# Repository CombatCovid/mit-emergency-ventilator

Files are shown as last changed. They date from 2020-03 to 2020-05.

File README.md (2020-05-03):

---
# basis test for remote pickup of metadata by both client app and 
# the essential repo updates system to come. 
# *todo* ground rules for yaml lines of this file, to be written 

# note carefully that this is the title that will show 
# in the Finder-Viewer app, and so _must_ be short enough to fit
# the longTitle below lets such be in meta; no place to use it at present
shortTitle: MIT Emergency Ventilator (E-Vent)
# these names are fixed labels as must be used on repo by GitHub API, for our access
name: mit-emergency-ventilator
nameWithOwner: CombatCovid/mit-emergency-ventilator

# markdown titles too long for Finder to show especially, we hold for any uses
# the same for long descriptions in the languages
# when text may fit, then they are the same in topic and longTopic yaml items
longTitle: MIT Emergency Ventilator (E-Vent) Project

languages:
  EN:
    description: A low-cost ventilator, based on the collective wisdom of many clinicians
    keywords: [patient,recovery,critical care,intensive care,icu,equipment,
      emergency room,helper,treatment,hospital,operating room]
    longDescription: >
      A ventilator is a machine that provides mechanical ventilation 
      by moving breathable air into and out of the lungs, to deliver breaths
      to a patient who is physically unable to breathe, 
      or breathing insufficiently.

  ES:
    description: Un ventilador de bajo costo, basado en la sabiduría colectiva de muchos médicos.
    keywords: [ paciente,recuperación,Cuidado crítico,
      cuidados intensivos,icu,equipo,sala de emergencias,
      ayudante,tratamiento,hospital,sala de operaciones ]
    longDescription: >
      Un ventilador es una máquina que proporciona ventilación mecánica.
      moviendo aire respirable dentro y fuera de los pulmones, 
      para entregar respiraciones a un paciente que es físicamente 
      incapaz de respirar, o respirando insuficientemente.
      
  KR:
    keywords: [ 환자,회복,중요한 치료,집중 치료,아이쿠,장비,
      응급실,돕는 사람,치료,병원,수술실 ]
    description: 많은 임상의의 집단적 지혜에 기반한 저렴한 인공 호흡기
    longDescription: >
      인공 호흡기는 기계적 환기를 제공하는 기계입니다
      통기성 공기를 폐 안팎으로 이동시켜 호흡
      신체적으로 숨을 쉴 수없는 환자에게
      또는 호흡이 불충분합니다.
 
project-link: https://e-vent.mit.edu/
intended-use: >-
    tbd
made: true
made-independently: false
license:
  hardware: undefined
okh-manifest-version: 1.0.0
date-updated: 2020-03-31
manifest-author:
  name: MiT people
  affiliation: MIT
contributors:
  undefined
sub-parts:
  undefined
  undefined
  
---

# Title: MIT Emergency Ventilator (E-Vent) Project

### References: 

All the information compiled here is from the [MIT Emergency Ventilator (E-Vent) Project](https://e-vent.mit.edu/)

To download our repo: [**DOWNLOAD**](https://github.com/CombatCovid/mit-emergency-ventilator/archive/master.zip)

This is the url of our repo : [https://github.com/CombatCovid/mit-emergency-ventilator](https://github.com/CombatCovid/mit-emergency-ventilator)

## Background & Need

We are one of several teams who recognized the challenges faced by Italian physicians, and are working to find a solution to the anticipated global lack of ventilators. In the US alone, the COVID-19 pandemic may cause ventilator shortages on the order of 300,000-700,000 units (CDC Pandemic Response Plans). These could present on a national scale within weeks, and are already being felt in certain areas. An increase in conventional ventilator production is very likely to fall short and with significant associated cost (paywall warning).

Almost every bed in a hospital has a manual resuscitator (Ambu-Bag) nearby, available in the event of a rapid response or code where healthcare workers maintain oxygenation by squeezing the bag. Automating this appears to be the simplest strategy that satisfies the need for low-cost mechanical ventilation, with the ability to be rapidly manufactured in large quantities. However, doing this safely is not trivial.

Use of a bag-valve mask (BVM) in emergency situations is not a new concept. A portable ventilator utilizing an ambu-bag was introduced in 2010 by a student team in the MIT class 2.75 Medical Device Design (original paper here and news story here), but did not move past the prototype stage. Around the same time, a team from Stanford developed a lower-cost ventilator for emergency stockpiles and the developing world. It looks similar to a modern ICU ventilator (Onebreath), but “production for US hospitals would start [in] about 11 months”, making it “a second wave solution” (MIT Tech Review Article). Last year, the AMBU® Bag concept was re-visited by two student teams, one from Rice university (here & here), and another Boston-based team who won MIT Sloan’s Healthcare prize (MIT News: Umbilizer). Other teams currently working on this challenge can be found linked on our “Additional Resources” page.

## Key Research Question

We have launched an emergency research project with a team of MIT Engineers and American clinicians to address the question:

**Is it possible to safely ventilate a COVID-19 patient by automatically actuating a manual resuscitator?**

Our process in approaching this question is to first identify the minimum requirements for a low-cost ventilator, based on the collective wisdom of many clinicians, design against these requirements, conduct immediate testing, report the results, iterate and facilitate discussion.

Manual ventilation with an Ambu-bag is a short-term solution in a critical care environment, without any apparent clinical evidence regarding the safety of long-term use (days-weeks). There are multiple scenarios in which respiratory support could be needed: patients can be awake or asleep, sedated or sedated and paralyzed, breathing spontaneously, weaning off of a vent, etc. Furthermore, changing clinical presentations with ARDS require shifting minute ventilation (tidal volume x respiratory rate) to “lung-protective” strategies, which place patient’s at risk for things like auto-PEEP. Some of these situations are simpler than others, with the simplest being ventilating a sedated, paralyzed patient, and at a minimum a safe emergency ventilator could be used in such a situation to free-up a conventional ventilator.

Any solution should be utilized only in a healthcare setting with direct monitoring by a clinical professional. While it cannot replace an FDA-approved ICU ventilator, in terms of functionality, flexibility, and clinical efficacy, the MIT E-Vent is anticipated to have utility in helping free up existing supply or in life-or-death situations when there is no other option.

Further, any low-cost ventilator system must take great care regarding providing clinicians with the ability to closely control and monitor tidal volume, inspiratory pressure, bpm, and I/E ratio, and be able to provide additional support in the form of PEEP, PIP monitoring, filtration, and adaptation to individual patient parameters. We recognize, and would like to highlight for anyone seeking to manufacture a low-cost emergency ventilator, that failing to properly consider these factors can result in serious long-term injury or death.

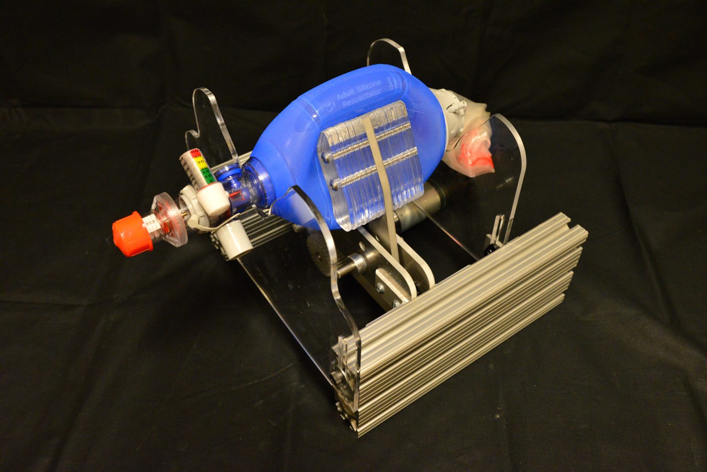
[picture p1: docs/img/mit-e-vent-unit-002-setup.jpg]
MIT E-vent Unit 002 setup


## Open Source Design
At the present time, we are producing four sets of material, which we will be releasing and updating on this site in an open-source fashion:

1. Minimum safe ventilator functionality based on clinical guidance
2. Reference hardware design for meeting minimum clinical requirements
3. Reference control strategies and electronics designs and supporting insights
4. Results from testing in animal models

We are releasing this material with the intent to provide those with the ability to make or manufacture ventilators, the tools needed to do so in a manner that seeks to ensure patient safety. Clinicians viewing this site can provide input and expertise and report on their efforts to help their patients.

As with any research to design to scale-up to manufacture, we anticipated that there will be many problems and it is our goal to provide this site as a tool to “close the loop” and receive feedback. We will also do our best to publish the most relevant pieces of information in the discussion forum for all to see.

We invite anyone who is interested to follow this work.

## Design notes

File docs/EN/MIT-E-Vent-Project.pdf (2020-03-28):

# MIT Emergency Ventilator (E-Vent) Project

## Contents

1 Title: MIT Emergency Ventilator (E-Vent) Project | 2
1.0.1 | References: | | 2
1.1 Background & Need | | 2
1.2 Key Research Question | | 2
1.3 Open Source Design | | 3
2 Key Ventilation Specifications | 4
3 Mechanical design | 4
3.1 Files to download | | 5
3.2 Documentation useful pictures | | 5
3.2.1 | Early design (Unit 001) | | 9
4 Electrical Design | 9
4.1 Motor & Encoder | | 9
4.1.1 | Motor Options: | | 9
4.2 Power Supply | | 13
4.3 Controller | | 14
4.4 Motor Driver | | 14
4.5 Inputs | | 14
4.6 Output | | 15
4.7 Audible alert buzzer will identify multiple fault conditions | | 15
5 Testing results | 16
5.1 Study 1 – 20 March 2020 | | 16
5.1.1 | Key Learnings (more results will be forthcoming) | | 16
5.1.2 | Next Steps | | 16

## List of Figures

1 | MIT E-vent Unit 002 setup | | 3
2 | Plates to support the bag | | 10
3 | Unit 002-most updated design | | 11
4 | Electrical System Architecture | | 12
5 | Andy Mark AM 2971 gearmotor | | 13
6 | RoboClaw Solo motor controller | | 15

## 1 Title: MIT Emergency Ventilator (E-Vent) Project

### 1.0.1 References:

All the information compiled here is from the MIT Emergency Ventilator (E-Vent) Project (https://e-vent.mit.edu/)

To download our repo: DOWNLOAD (https://github.com/CombatCovid/mit-emergency-ventilator/archive/master.zip)

This is the url of our repo : https://github.com/CombatCovid/mit-emergency-ventilator

### 1.1 Background & Need

We are one of several teams who recognized the challenges faced by Italian physicians, and are working to find a solution to the anticipated global lack of ventilators. In the US alone, the COVID-19 pandemic may cause ventilator shortages on the order of 300,000-700,000 units (CDC Pandemic Response Plans). These could present on a national scale within weeks, and are already being felt in certain areas. An increase in conventional ventilator production is very likely to fall short and with significant associated cost (paywall warning).

Almost every bed in a hospital has a manual resuscitator (Ambu-Bag) nearby, available in the event of a rapid response or code where healthcare workers maintain oxygenation by squeezing the bag. Automating this appears to be the simplest strategy that satisfies the need for low-cost mechanical ventilation, with the ability to be rapidly manufactured in large quantities. However, doing this safely is not trivial.

Use of a bag-valve mask (BVM) in emergency situations is not a new concept. A portable ventilator utilizing an ambu-bag was introduced in 2010 by a student team in the MIT class 2.75 Medical Device Design (original paper here and news story here), but did not move past the prototype stage. Around the same time, a team from Stanford developed a lower-cost ventilator for emergency stockpiles and the developing world. It looks similar to a modern ICU ventilator (Onebreath), but “production for US hospitals would start [in] about 11 months”, making it “a second wave solution” (MIT Tech Review Article). Last year, the AMBU® Bag concept was re-visited by two student teams, one from Rice university (here & here), and another Boston-based team who won MIT Sloan’s Healthcare prize (MIT News: Umbilizer). Other teams currently working on this challenge can be found linked on our “Additional Resources” page.

### 1.2 Key Research Question

We have launched an emergency research project with a team of MIT Engineers and American clinicians to address the question:

Is it possible to safely ventilate a COVID-19 patient by automatically actuating a manual resuscitator?

Our process in approaching this question is to first identify the minimum requirements for a low-cost ventilator, based on the collective wisdom of many clinicians, design against these requirements, conduct immediate testing, report the results, iterate and facilitate discussion.

Manual ventilation with an Ambu-bag is a short-term solution in a critical care environment, without any apparent clinical evidence regarding the safety of long-term use (days-weeks). There are multiple scenarios in which respiratory support could be needed: patients can be awake or asleep, sedated or sedated and paralyzed, breathing spontaneously, weaning off of a vent, etc. Furthermore, changing clinical presentations with ARDS require shifting minute ventilation (tidal volume x respiratory rate) to “lung-protective” strategies, which place patient’s at risk for things like auto-PEEP. Some of these situations are simpler than others, with the simplest being ventilating a sedated, paralyzed patient, and at a minimum a safe emergency ventilator could be used in such a situation to free-up a conventional ventilator.

Any solution should be utilized only in a healthcare setting with direct monitoring by a clinical professional. While it cannot replace an FDA-approved ICU ventilator, in terms of functionality, flexibility, and clinical efficacy, the MIT E-Vent is anticipated to have utility in helping free up existing supply or in life-or-death situations when there is no other option.

Further, any low-cost ventilator system must take great care regarding providing clinicians with the ability to closely control and monitor tidal volume, inspiratory pressure, bpm, and I/E ratio, and be able to provide additional support in the form of PEEP, PIP monitoring, filtration, and adaptation to individual patient parameters. We recognize, and would like to highlight for anyone seeking to manufacture a low-cost emergency ventilator, that failing to properly consider these factors can result in serious long-term injury or death.


Figure 1: MIT E-vent Unit 002 setup

### 1.3 Open Source Design

At the present time, we are producing four sets of material, which we will be releasing and updating on this site in an open-source fashion:

1. Minimum safe ventilator functionality based on clinical guidance
2. Reference hardware design for meeting minimum clinical requirements
3. Reference control strategies and electronics designs and supporting insights
4. Results from testing in animal models

We are releasing this material with the intent to provide those with the ability to make or manufacture ventilators, the tools needed to do so in a manner that seeks to ensure patient safety. Clinicians viewing this site can provide input and expertise and report on their efforts to help their patients.

As with any research to design to scale-up to manufacture, we anticipated that there will be many problems and it is our goal to provide this site as a tool to “close the loop” and receive feedback. We will also do our best to publish the most relevant pieces of information in the discussion forum for all to see.

We invite anyone who is interested to follow this work.

## 2 Key Ventilation Specifications

From the Clinical Guidance this document summarizes the minimum set of requirements for ventilation:

1. Patients must be under the management of a trained clinician.
2. The minimum controllable parameters in order to ventilate a patient include:
- BPM (breaths per minute): between 8 – 30 BPM
- Tidal Volume (air volume pushed into lung): between 200 – 800 mL based on patient weight
- I/E Ratio (inspiratory/expiration time ratio): recommended to start around 1:2; best if adjustable between range of 1:1 – 1:4¹
- Assist Detection pressure. When a patient tries to inspire, they can cause a dip on teh order of 1 – 5 cm H2O, with respect to PEEP pressure (not necessarily = atmospheric).
3. Airway pressure must be monitored
- Maximum pressure should be limited to 40 cm H2O at any time; Plateau pressure should be limited to max 30 cm H2O
- The use of a passive mechanical blow-off valve fixed at 40 cm H2O is strongly recommended
- Clinician require readings of plateau pressure and PEEP (refer to clinical documentation tab)
- PEEP of 5-15 cm H2O required; many patients need 10-15 cmH2O
4. Failure conditions must permit conversion to manual clinician override, i.e. if automatic ventilation fails, the conversion to immediate ventilation must be immediate.
5. Ventilation on room air is better than no ventilation at all. Blending of oxygen and air gas mixture to adjust FiO2 is not important in an emergency scenario. It is certainly nice to have that ability and can easily be implemented with a oxygen / air gas blender that some hospitals already have.
6. Covid-19 can get aerosolized (airborne), so HEPA filtration on the patient’s exhalation is required or between the ventilator unit and the patient (at the end of the endotracheal tube) to protect clinical staff from certain infection. In-line HEPA filters can usually be purchased alongside manual resuscitator bags.
7. Heat and moisture exchanger should be used in line with the breathing circuit.
8. Failure conditions must result in an alarm.

This is a minimal requirement set for emergency use. Equipment designed for more regular use, even if for emerging markets, will require additional features to be used on a regular basis.

## 3 Mechanical design

How does the E-vent looks like?

See how the emergency ventilator works here (https://e-vent.mit.edu/wp-content/uploads/2020/03/002-bench-testing-scaled-1.mp4)

1Range determined based on several COVID-19 patients’ ventilator settings reported from Boston area ICUs

### 3.1 Files to download

Follow this link where there are all the .dxf files.

This section documents the mechanical design of the MIT E-Vent.

Please understand that we are designing, testing and posting information as fast as we can. We have no hidden information and more detailed plans will post as soon as we draw them!

Note: Any mechanical design must meet the specifications outlined in the Getting started section.

This is a prototype. We are in process of testing and refining this concept design to increase robustness. The basic concept consists of two arms that gently close in sync to compress the bag. This must be coupled with a closed loop control system. Major mechanical design requirements included:

- Be nice to your bag and its hoses! Up to 2x7x24X60x30 = 604,800 cycles.
- Fail-Safe operation! If the machine fails, a clinician must be able to convert to manual bagging.
- Keep It Simple & Make It Super! Enable others to fabricate.
- Many drive motor possibilities! Enable multiple motors and configurations.

The Units version 002 shown here were developed to maximize flexibility during testing, so that the bag and motor position could be adjusted. None of this adjustability is needed once a particular bag is selected.

The basic dimensions are now set and any skilled mechanical designer will be able to execute this design and adjust it to suit locally available materials and fabrication technologies.

We have ready access to waterjet and laser cutters and 80/20 components, however these parts can be CNC milled and bolted and welded to your specification

### 3.2 Documentation useful pictures

Caution: Forces and torques are much higher than expected when an Ambu bag is connected to a human respiratory system pressures can range up to 40 cm H2O and, potentially, even higher depending on breath rate. There must be a pressure release valve set at 40 cm H2O; without this higher pressures will risk permeant injury or death. Diseased lungs can have compliance on the order of 10x lower than that of healthy patients and this further compounds the problem.

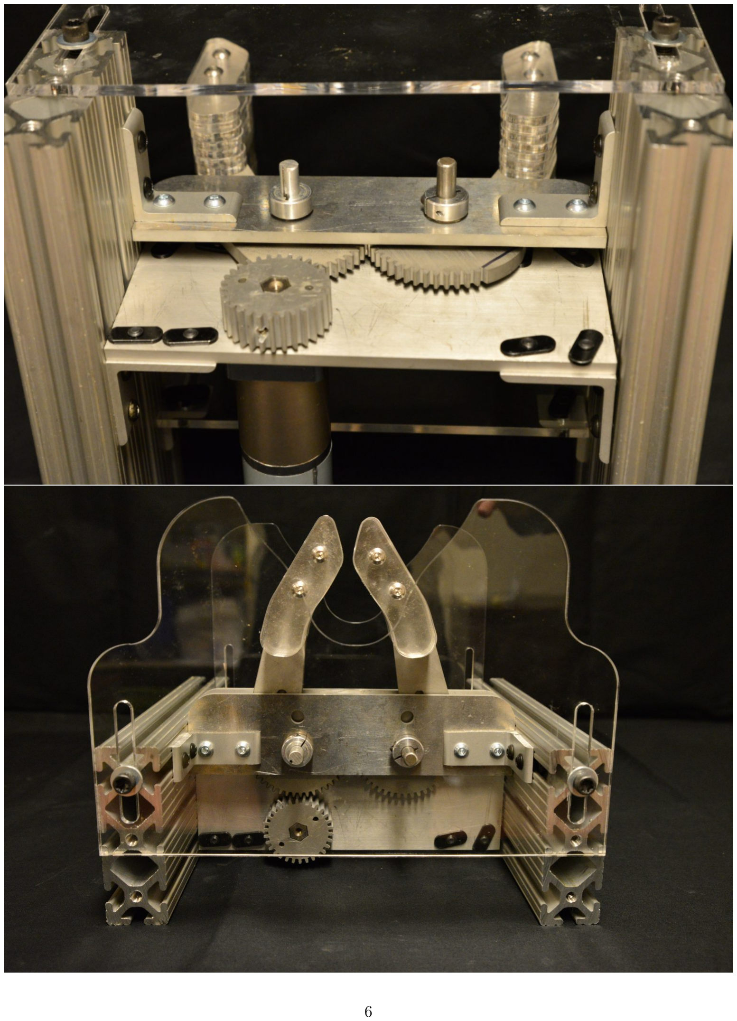
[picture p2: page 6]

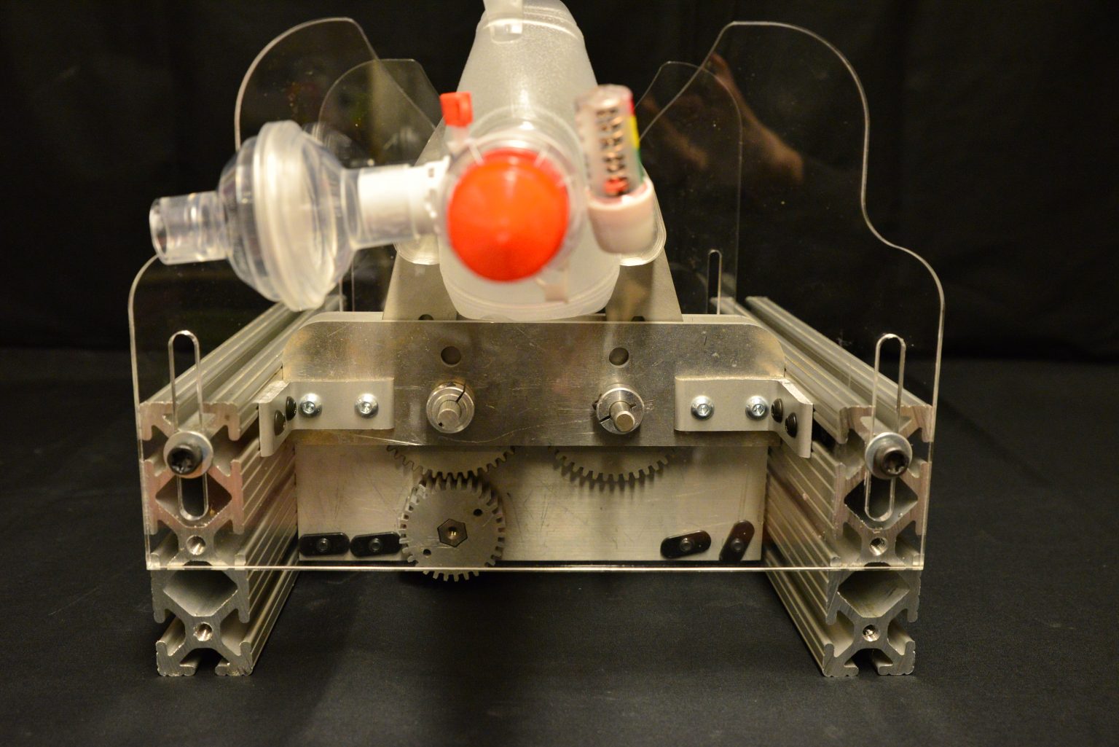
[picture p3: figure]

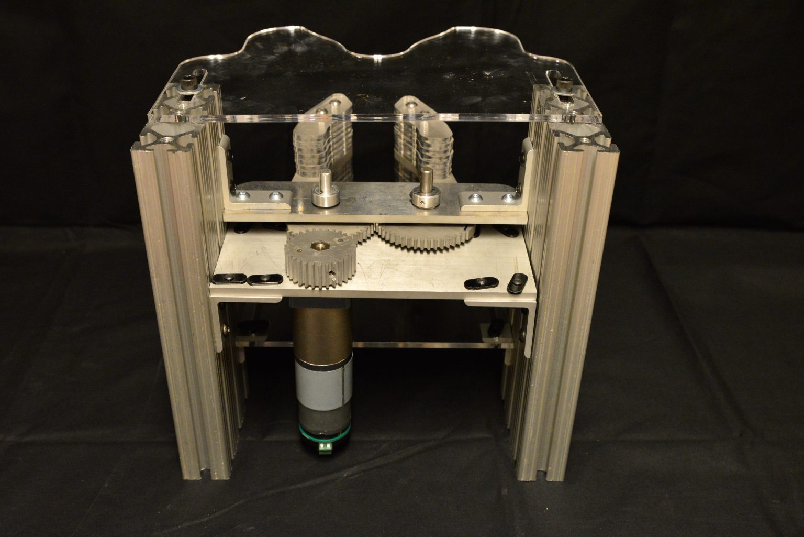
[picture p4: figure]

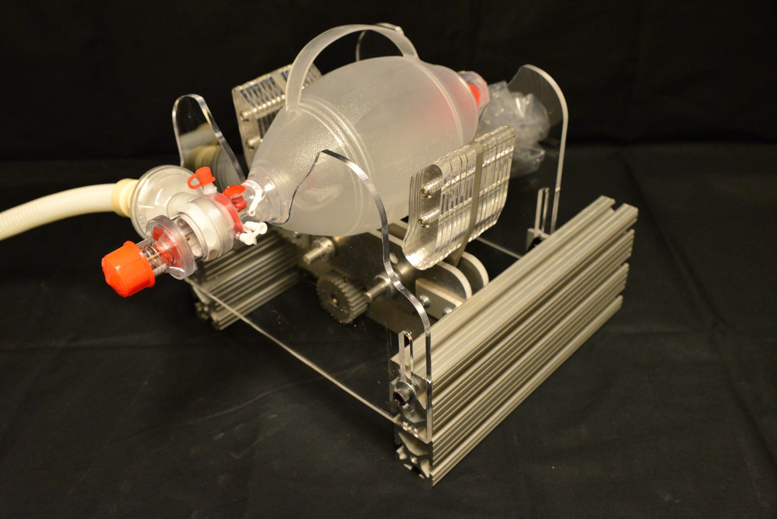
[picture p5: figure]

### 3.2.1 Early design (Unit 001)

An early prototype unit is show below in laser cut acrylic. Unit 001 was similar and underwent testing. Unit 002 been fabricated with an 80/20 metal frame, to address durability and maximise flexibility during testing, is undergoing testing today.

The collection of pictures from early designs are found in this folder

## 4 Electrical Design

This section shows a description of the minimum hardware set required to control the ventilator as described in the other documentation.

### 4.1 Motor & Encoder

The mechanical system should be driven with a motor under closed loop control. For feedback measurement, we are using a quadrature encoder on the motor, and a potentiometer (POT) on the moving arms to measure the absolute angle.

### 4.1.1 Motor Options:

Brushed DC motor with gearbox and position feedback. Any sufficiently high-torque, back-driveable motor with angle sensing, integrated or separated, should work. Power is estimated at 36 W or greater, with a safety factor recommended.

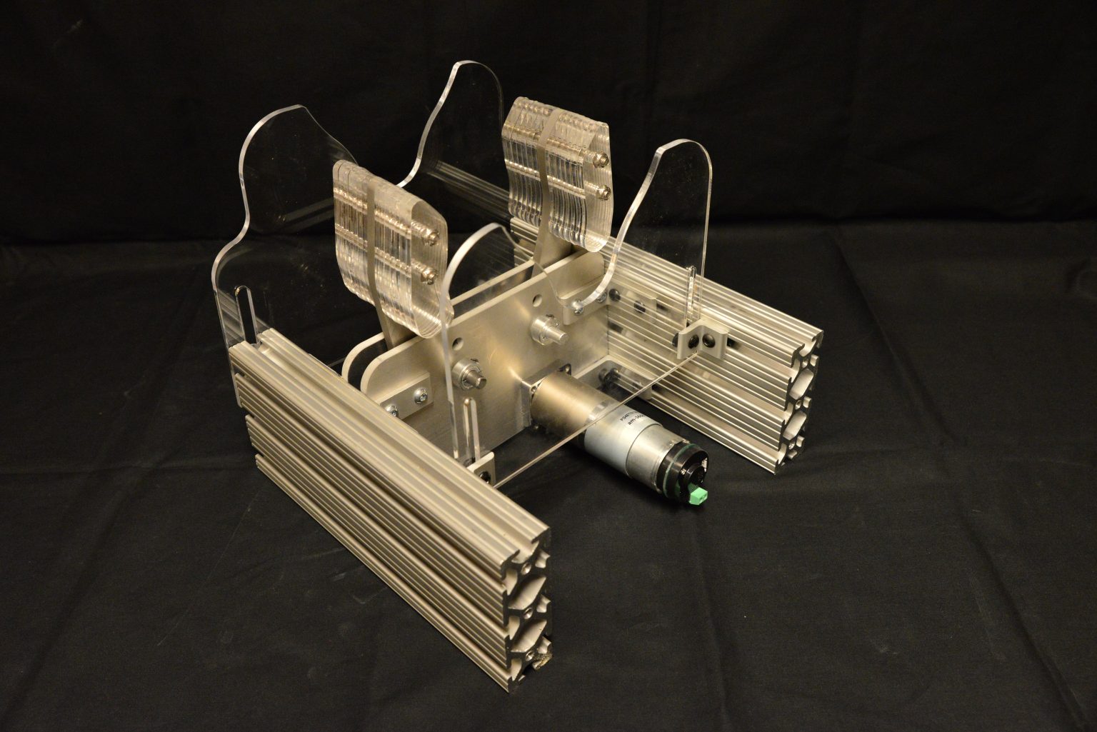
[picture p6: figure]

Figure 2: Plates to support the bag

Figure 3: Unit 002-most updated design

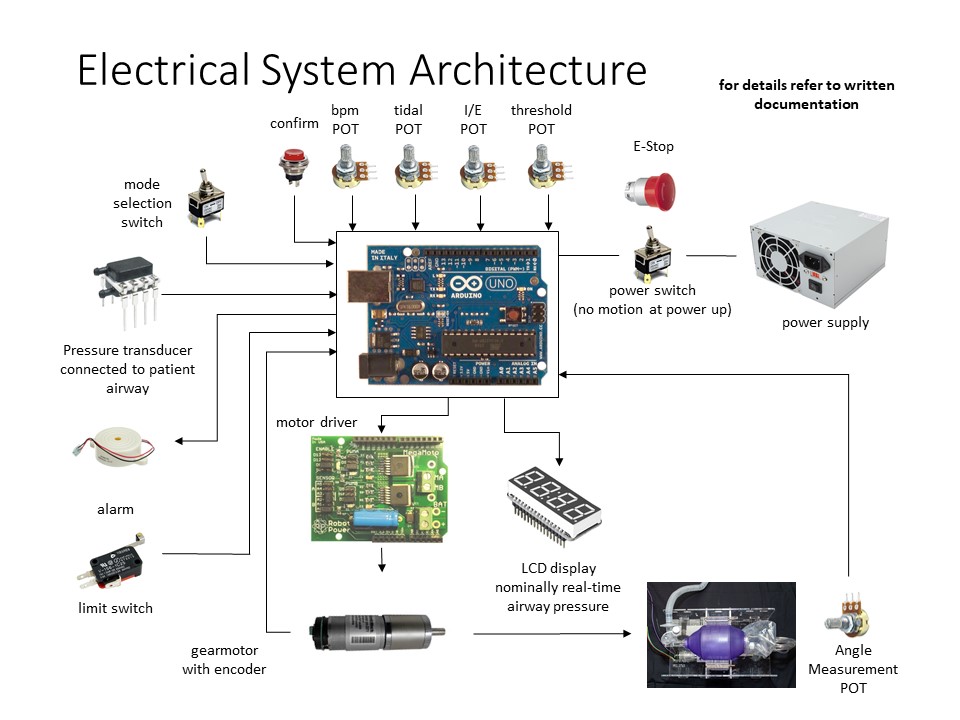
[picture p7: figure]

Figure 4: Electrical System Architecture

Caution: If a stepper motor is used, position should still be taken from the angle sensor so that missed steps do not cause position drift

Caution: The motor and mechanism, together, must be back drivable in order to move the mechanism by hand, remove the bag and immediately convert to manual bagging.

- Assumed nominal operating parameters: Referencing clinical documentation: max 25 breath-per-minute (bpm), and up to a 1:3 Inspiration: Expiration Ratio (I:E ratio) (ex: bag squeezed for 1 time units, bag relaxed for 3 time units). Note that COVID-19 patients may need greater I:E ratios.
- Prototype component: Andy Mark AM 2971 gearmotor. (https://sites.google.com/site/frc5064/parts/motors-and-gearboxes/-pg71-planetary-gearbox-with-rs775-motor-and-encoder)

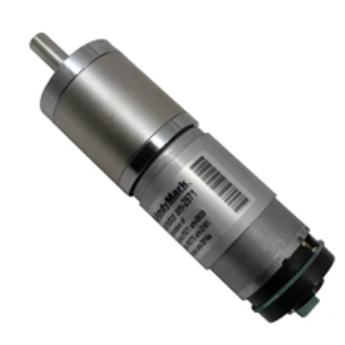
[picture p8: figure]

Figure 5: Andy Mark AM 2971 gearmotor

This was scavenged from a FIRST Robotics kit, it is suitable for testing, but has not been proved for safe longer-term use. Builders will need to source another motor.

While the machine should be capable of operating continuously at max tidal volume and max bpm, in practice medical professionals often do not operate with large tidal volume and high bpm simultaneously. In normal operation, I:E ratios around 1:2 and 12 bpm are a decent central design point. Tidal volume as a function of position needs to be calibrated.

Caution: In deployed use, the motor must be able to operate continuously for several days, 100% duty cycle. This may require larger motors than expected or increased motor cooling to prevent overheating.

### 4.2 Power Supply

Nominally, a power supply that can deliver 12 V and 5 A is expected to work. Rapid deceleration of the motor causes supply-voltage spikes and must be avoided via correct motor motion profile design. Capacitors should be added across the H-Bridge power leads for extra protection.

An alternate power supply would be to use a car battery with a 5 A car battery charger connected. This will allow for very high instantaneous power draws and voltage spike absorption. The battery will double as a ~2-3 hour backup in case of building power loss.

### 4.3 Controller

Microcontroller for timing, measuring, and actuating: Arduino Uno (https://www.arduino.cc/en/Guide/ArduinoUno) – readily available and easy to program, with extensive online support and documentation. It provides 6 A/D pins (for potentiometers and pressure sensors) and 13 digital I/O pins, including dedicated hardware interrupts (for encoders) and PWM pins for H-bridge driving. Other industry validated controllers can be used, and we may implement them in the

future.

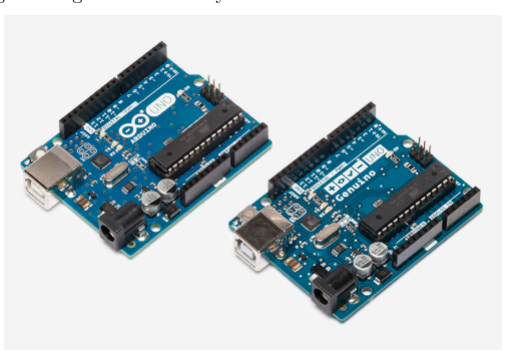
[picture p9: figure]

### 4.4 Motor Driver

Use any motor driver with sufficient voltage and current ratings to meet the motor power specifications. Closed loop servo controllers can also be employed. Our control strategy is PWM with a H Bridge. For fastest implementation using cheap, off-the-shelf parts, we recommend an Arduino compatible motor shield.

For reference, we are using a RoboClaw Solo motor controller (https://www.pololu.com/product/3290) to control a brushed DC gear motor. The RoboClaw firmware uses a velocity PID controller and a position PID controller to command the motor to a desired position at a desired velocity. The PID values must be tuned in advance. Other motor controllers with similar functions will work, we do not recommend any specific controller.

### 4.5 Inputs

Control knob potentiometers (POTs) should all be single turn, 10 KΩ. Single turn is to allow for specific settings to be marked on the face plate.

Pressure sensor – Receives a voltage proportional to the pressure in the patient’s lungs. Used to determine max pressure reached during inspiration, and to trigger when the patient is attempting to breathe in during assist mode. Pressure sensor selected should be differential (to sense negative pressures) with a range of up to 100 cm H2O. This is a 2x safety factor. Our sensors are sourced from Honeywell.

Note on Plumbing: The pressure sensor must be connected to the Ambu bag’s sensing port or somewhere in the airflow, as close as possible to the patient, past any valves.

POT 1 – Varies inspired volume, sets angular oscillation of the arms. During operation, each arm varies by a maximum of approximately 20 grades, corresponding to fully squeezing a large bag. This dial varies position from 0% (fully open) to 100% (fully compressed).

POT 2 – Varies the BPM. This sets the rate from 0 to the maximum BPM given in the clinical document.

POT 3 – Varies the I:E ratio. Range as given in the clinical document.

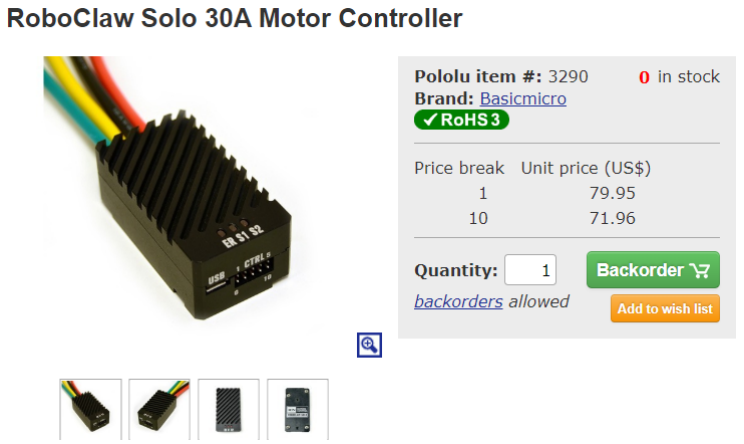
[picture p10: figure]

Figure 6: RoboClaw Solo motor controller

Note: It is not essential that this be settable, one value greater than 1:1 can be selected and the POT repurposed as a threshold for over pressure. (Multiple clinicians have indicated that varying I:E is not critical.)

POT 4– Sets the pressure threshold for detecting assist control. This varies as described in the clinical document.

Pushbutton Switch – Confirms user selection of new POT setting. This is an important safety.

Switch – Power on / off

E-stop – Instantly deactivates the system.

Switch – Mode selection from volume to assist control.

Limit Switch – Used for homing the arms positions.

### 4.6 Output

LCD screen displays airway pressure in cm H2O. Other functions can be incorporated later. We are using a 20×4 character LCD display as this will display the minimum information, described in under interface. Any display better than this will be sufficient.

4.7 Audible alert buzzer will identify multiple fault conditions.

title: “MIT Emergency Ventilator (E-Vent) Project” output: pdf_document documentclass: article classoption: onecolumn pdf_document: latex_engine: pdflatex toc: true lof: true numberSections: true highlight: tango sectionsDepth: 3 chapters: True figPrefix: - “Fig.” - “Figs.” secPrefix: - “Section” -“Sections” fontsize: 12pt geometry: margin=0.5in autoEqnLabels: true cref: true crossref: true colorlinks: true —

## 5 Testing results

They are working with certified animal testing labs to conduct studies in animal models under IACUC-Institutional Animal Care and Use Committee (https://olaw.nih.gov/resources/tutorial/iacuc.htm) approved protocols. A porcine model was chosen as pigs have a respiratory systems that is most similar to human beings. This is essential in order to evaluate system performance and safety. We would like to anonymously acknowledge the laboratory staff for their tireless efforts, and the donors who are enabling this rapid scale-up of animal testing.

### 5.1 Study 1 – 20 March 2020

Porcine study Nr 1 was conducted at a leading research facility in the Boston area. In addition to the facility staff (veterinarians, technologists, and Study), our on-site team consisted of Emergency Medicine and Anesthesia physicians working along side mechanical design, manufacturing, controls, and electrical engineers. The goals of this study were as follows:

- Conduct a functional test of the prototype MIT E-Vent Unit 001.
- Compare ventilation with the E-Vnet to that of a Puritan Bennet 840 Ventilator system (2016 model year, Medtronic) (https://www.medtronic.com/covidien/en-us/products/mechanical-ventilation/puritan-bennett-840-ventilator.html) graciously loaned to us.

### 5.1.1 Key Learnings (more results will be forthcoming)

- We identifies deficiencies in the all-laser cut design. We have already transitioned to a metal frame design.
- We more accurately defined key parameters related to power requirements for a drive system.
- We investigated potential control strategies and identified key UI/UX requirements as well as human factors.
- We determined key pressures when connected to a real lung and with PEEP set.

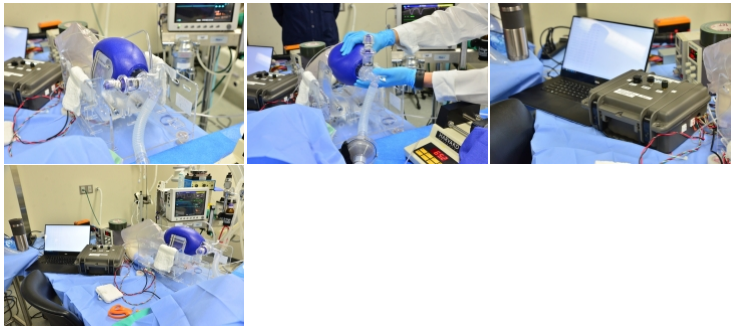
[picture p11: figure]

### 5.1.2 Next Steps

The next study will conduct a functional test Unit 002 in a similar porcine model.

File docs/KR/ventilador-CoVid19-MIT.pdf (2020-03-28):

# Proyecto ventilador de emergencia del MIT (E-Vent)

## Contents

1 Título: Proyecto ventilador de emergencia del MIT (E-Vent) | 2
1.0.1 | Referencia: | | 2
1.1 Antecedentes y necesidad | | 2
1.2 Pregunta clave de investigación | | 2
1.3 Diseño de código abierto | | 4
2 Especificaciones clave de ventilación | 4
2.1 Este es un requisito mínimo establecido para uso de emergencia. Los equipos diseñados para
un uso más regular, incluso para mercados emergentes, requerirán características adicionales
para su uso regular | | 5
3 Diseño Mecanico | 5
3.1 Ficheros para descargar | | 5
3.2 Documentación de imágenes útiles | | 6
3.2.1 | Diseño temprano (Unidad 001) | | 10
4 Diseño electrico | 10
4.1 Motor y codificador | | 10
4.1.1 | Opciones de motor: | | 10
4.2 Fuente de alimentación | | 14
4.3 Controlador | | 15
4.4 Motor Driver | | 15
4.5 Entradas | | 15
4.6 Salida | | 16
4.7 El zumbador de alerta audible identificará múltiples condiciones de falla | | 17
5 Resultados de la prueba | 17
5.1 Estudio 1 - 20 de marzo de 2020 | | 17
5.1.1 | Aprendizajes clave (se obtendrán más resultados) | | 17
5.1.2 | Próximos pasos | | 18

## List of Figures

1 | MIT E-vent Unit 002 setup | | 3
2 | Plates to support the bag | | 11
3 | Unit 002-most updated design | | 12
4 | Arquitectura del Sistema Electrico | | 13
5 | Andy Mark AM 2971 gearmotor | | 14

6 | RoboClaw Solo motor controller | | 16

## 1 Título: Proyecto ventilador de emergencia del MIT (E-Vent)

### 1.0.1 Referencia:

Toda la información compilada aquí se puede encontrar [en este enlace] (https://e-vent.mit.edu/)

Para descargar el repo: DOWNLOAD (https://github.com/CombatCovid/mit-emergency-ventilator/archive/master.zip)

El url del repositorio: https://github.com/CombatCovid/mit-emergency-ventilator

### 1.1 Antecedentes y necesidad

Somos uno de los varios equipos que reconocieron los desafíos que enfrentan los médicos italianos y estamos trabajando para encontrar una solución a la anticipada falta global de ventiladores. Solo en los EE. UU., La pandemia de COVID-19 puede causar escasez de ventiladores del orden de 300,000-700,000 unidades (Planes de respuesta a la pandemia de los CDC). Estos podrían presentarse a escala nacional en semanas, y ya se están sintiendo en ciertas áreas. Es muy probable que un aumento en la producción de ventiladores convencionales se quede corto y con un costo asociado significativo (advertencia del muro de pago).

Casi todas las camas en un hospital tienen un resucitador manual (Ambu-Bag) cerca, disponible en caso de una respuesta rápida o un código donde los trabajadores de la salud mantienen la oxigenación apretando la bolsa. La automatización de esta parece ser la estrategia más simple que satisface la necesidad de ventilación mecánica de bajo costo, con la capacidad de fabricarse rápidamente en grandes cantidades. Sin embargo, hacer esto de manera segura no es trivial.

El uso de una máscara de válvula de bolsa (BVM) en situaciones de emergencia no es un concepto nuevo. En 2010, un equipo de estudiantes del MIT clase 2.75 Diseño de dispositivos médicos (documento original aquí y noticia aquí) introdujo un ventilador portátil que utilizaba una bolsa ambu, pero no pasó de la etapa del prototipo. Casi al mismo tiempo, un equipo de Stanford desarrolló un ventilador de menor costo para las reservas de emergencia y el mundo en desarrollo. Se parece a un ventilador moderno de la UCI (Onebreath), pero “la producción para los hospitales de EE. UU. Comenzaría [en] aproximadamente 11 meses”, lo que lo convierte en “una solución de segunda ola” (Artículo de revisión técnica del MIT). El año pasado, dos equipos de estudiantes volvieron a visitar el concepto AMBU® Bag, uno de la universidad Rice (aquí y aquí) y otro equipo con sede en Boston que ganó el premio MIT Sloan’s Healthcare (MIT News: Umbilizer). Otros equipos que trabajan actualmente en este desafío se pueden encontrar vinculados en nuestra página de “Recursos adicionales”.

### 1.2 Pregunta clave de investigación

Hemos lanzado un proyecto de investigación de emergencia con un equipo de ingenieros del MIT y clínicos estadounidenses para abordar la pregunta:

¿Es posible ventilar de manera segura a un paciente con COVID-19 accionando automática-mente un reanimador manual?

Nuestro proceso para abordar esta pregunta es identificar primero los requisitos mínimos para un ventilador de bajo costo, basado en la sabiduría colectiva de muchos médicos, diseñar contra estos requisitos, realizar pruebas inmediatas, informar los resultados, repetir y facilitar la discusión.

La ventilación manual con una bolsa Ambu es una solución a corto plazo en un entorno de cuidados críticos, sin evidencia clínica aparente con respecto a la seguridad del uso a largo plazo (días-semanas). Existen múltiples escenarios en los que podría necesitarse soporte respiratorio: los pacientes pueden estar despiertos o dormidos, sedados o sedados y paralizados, respirar espontáneamente, destetar de un respiradero, etc. Además, cambiar las presentaciones clínicas con SDRA requiere un cambio de ventilación minuto (volumen corriente) x frecuencia respiratoria) a estrategias de “protección pulmonar”, que ponen al paciente en riesgo de cosas como auto-PEEP. Algunas de estas situaciones son más simples que otras, siendo la más simple la ventilación de un paciente paralizado y sedado, y como mínimo se podría usar un ventilador de emergencia seguro en tal situación para liberar un ventilador convencional.

Cualquier solución debe utilizarse solo en un entorno de atención médica con monitoreo directo por parte de un profesional clínico. Si bien no puede reemplazar un ventilador ICU aprobado por la FDA, en términos de funcionalidad, flexibilidad y eficacia clínica, se espera que el MIT E-Vent tenga utilidad para ayudar a liberar el suministro existente o en situaciones de vida o muerte cuando no hay otra opción.

Además, cualquier sistema de ventilación de bajo costo debe tener mucho cuidado con respecto a proporcionar a los médicos la capacidad de controlar y monitorear de cerca el volumen corriente, la presión inspiratoria, las ppm y la relación I / E, y poder brindar apoyo adicional en forma de PEEP, Monitoreo PIP, filtración y adaptación a parámetros individuales del paciente. Reconocemos, y nos gustaría resaltar para cualquiera que busque fabricar un ventilador de emergencia de bajo costo, que no considerar adecuadamente estos factores puede provocar lesiones graves o la muerte a largo plazo.


Figure 1: MIT E-vent Unit 002 setup

### 1.3 Diseño de código abierto

En la actualidad, estamos produciendo cuatro conjuntos de material, que lanzaremos y actualizaremos en este sitio de manera de código abierto:

1. Funcionalidad mínima segura del ventilador basada en orientación clínica
2. Diseño de hardware de referencia para cumplir con los requisitos clínicos mínimos
3. Estrategias de control de referencia y diseños electrónicos y conocimientos de apoyo.
4. Resultados de las pruebas en modelos animales.

Estamos lanzando este material con la intención de proporcionar a aquellos con la capacidad de fabricar o fabricar ventiladores, las herramientas necesarias para hacerlo de una manera que busque garantizar la seguridad del paciente. Los médicos que visitan este sitio pueden proporcionar información y experiencia e informar sobre sus esfuerzos para ayudar a sus pacientes.

Al igual que con cualquier investigación para diseñar, escalar y fabricar, anticipamos que habrá muchos problemas y nuestro objetivo es proporcionar este sitio como una herramienta para “cerrar el círculo” y recibir comentarios. También haremos todo lo posible para publicar la información más relevante en el foro de discusión para que todos la vean.

Invitamos a cualquier persona interesada a seguir este trabajo.

## 2 Especificaciones clave de ventilación

De la Guía clínica, este documento resume el conjunto mínimo de requisitos para la ventilación:

1. Los pacientes deben estar bajo la dirección de un clínico capacitado.
2. Los parámetros mínimos controlables para ventilar a un paciente incluyen:
- BPM (respiraciones por minuto): entre 8 - 30 BPM
- Volumen corriente (volumen de aire empujado hacia el pulmón): entre 200 - 800 ml según el peso del paciente
- Relación I / E (relación inspiratoria / tiempo de expiración): se recomienda comenzar alrededor de 1: 2; mejor si ajustable entre rango de 1:1 - 1:4¹
- Ayuda a la detección de presión. Cuando un paciente intenta inspirar, puede provocar una caída en el orden de 1 a 5 cm de H2O, con respecto a la presión de PEEP (no necesariamente = atmosférica).
3. La presión de la vía aérea debe ser monitoreada
- La presión máxima debe limitarse a 40 cm H2O en cualquier momento; La presión de la meseta debe limitarse a un máximo de 30 cm H2O
- Se recomienda encarecidamente el uso de una válvula de descarga mecánica pasiva fijada a 40 cm H2O
- El clínico requiere lecturas de presión de meseta y PEEP (consulte la pestaña de documentación clínica)
- Se requiere PEEP de 5-15 cm H2O; muchos pacientes necesitan 10-15 cmH $ _2 $ O
4. Las condiciones de falla deben permitir la conversión a anulación manual del médico, es decir, si la ventilación automática falla, la conversión a ventilación inmediata debe ser inmediata.
5. La ventilación en el aire de la habitación es mejor que no tener ventilación. La mezcla de oxígeno y aire y gas para ajustar FiO2 no es importante en un escenario de emergencia. Ciertamente es bueno

1Rango determinado en base a la configuración del ventilador de varios pacientes COVID-19 informados desde las UCI del área de Boston tener esa capacidad y puede implementarse fácilmente con un mezclador de oxígeno / aire que ya tienen algunos hospitales.
6. Covid-19 puede aerosolizarse (en el aire), por lo que se requiere filtración HEPA en la exhalación del paciente o entre la unidad de ventilación y el paciente (al final del tubo endotraqueal) para proteger al personal clínico de ciertas infecciones. Los filtros HEPA en línea generalmente se pueden comprar junto con bolsas de reanimación manuales.
7. El intercambiador de calor y humedad debe usarse en línea con el circuito de respiración.
8. Las condiciones de falla deben generar una alarma.

### 2.1 Este es un requisito mínimo establecido para uso de emergencia. Los equipos diseñados para un uso más regular, incluso para mercados

emergentes, requerirán características adicionales para su uso regular.

title: “Proyecto ventilador de emergencia del MIT (E-Vent)” output: pdf_document documentclass: article classoption: onecolumn pdf_document: latex_engine: pdflatex toc: true lof: true numberSections: true highlight: tango sectionsDepth: 3 chapters: True figPrefix: - “Fig.” - “Figs.” secPrefix: - “Section” -“Sections” fontsize: 12pt geometry: margin=0.5in autoEqnLabels: true cref: true crossref: true colorlinks: true —

## 3 Diseño Mecanico

Como es el E-vent en accion?

Para que veas como funciona E-vent dirigete aqui (https://e-vent.mit.edu/wp-content/uploads/2020/03/002-bench-testing-scaled-1.mp4)

### 3.1 Ficheros para descargar

Sigue este link donde estan todos los .dxf ficheros.

Esta sección documenta el diseño mecánico del MIT E-Vent.

Por favor, comprenda que estamos diseñando, probando y publicando información lo más rápido posible. ¡No tenemos información oculta y se publicarán planes más detallados tan pronto como los dibujemos!*

Nota: Cualquier diseño mecánico debe cumplir con las especificaciones descritas en la Sección de inicio.

Este es un prototipo. Estamos en proceso de probar y refinar este diseño conceptual para aumentar la robustez. El concepto básico consiste en dos brazos que se cierran suavemente sincronizados para comprimir la bolsa. Esto debe combinarse con un sistema de control de circuito cerrado. Los principales requisitos de diseño mecánico incluyen:

- ¡Sé amable con tu bolso y sus mangueras! Hasta 2x7x24X60x30 = 604,800 ciclos.
- ¡Operación a prueba de fallas! Si la máquina falla, un médico debe poder realizar la conversión a embolsado manual.
- ¡Mantenlo simple y hazlo súper! Permitir que otros fabriquen.
- ¡Muchas posibilidades de motor de accionamiento! Habilite múltiples motores y configuraciones.

Las Unidades versión 002 que se muestran aquí se desarrollaron para maximizar la flexibilidad durante las pruebas, de modo que la posición de la bolsa y el motor pudieran ajustarse. Nada de esta capacidad de ajuste es necesaria una vez que se selecciona una bolsa en particular.

Ahora se establecen las dimensiones básicas y cualquier diseñador mecánico experto podrá ejecutar este diseño y ajustarlo para adaptarse a los materiales disponibles localmente y las tecnologías de fabricación.

Tenemos acceso inmediato a cortadores de chorro de agua y láser y componentes 80/20, sin embargo, estas piezas se pueden fresar, atornillar y soldar con CNC según sus especificaciones.

### 3.2 Documentación de imágenes útiles

Precaución: las fuerzas y los pares son mucho más altos de lo esperado cuando una bolsa Ambu está conectada a un sistema respiratorio humano, las presiones pueden variar hasta 40 cm H2O y, potencialmente, incluso más, dependiendo de la frecuencia respiratoria. Debe haber una válvula de liberación de presión establecida a 40 cm H2O; sin esto, las presiones más altas correrán el riesgo de lesiones permanentes o la muerte. Los pulmones enfermos pueden tener un cumplimiento del orden de 10 veces menor que el de los pacientes sanos y esto agrava aún más el problema.

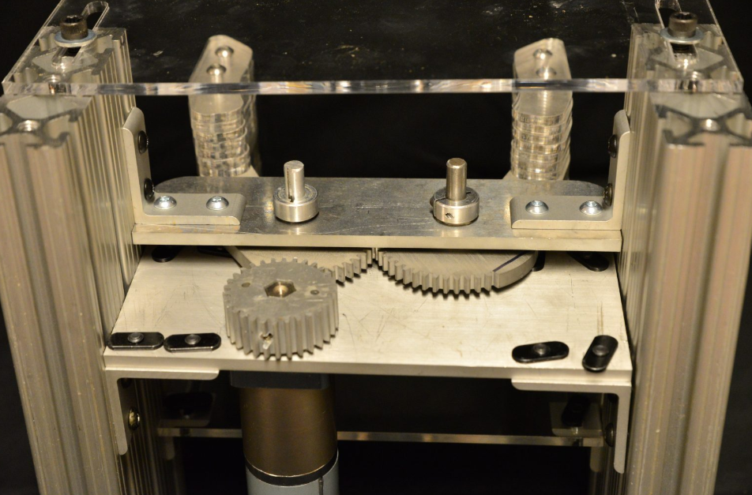
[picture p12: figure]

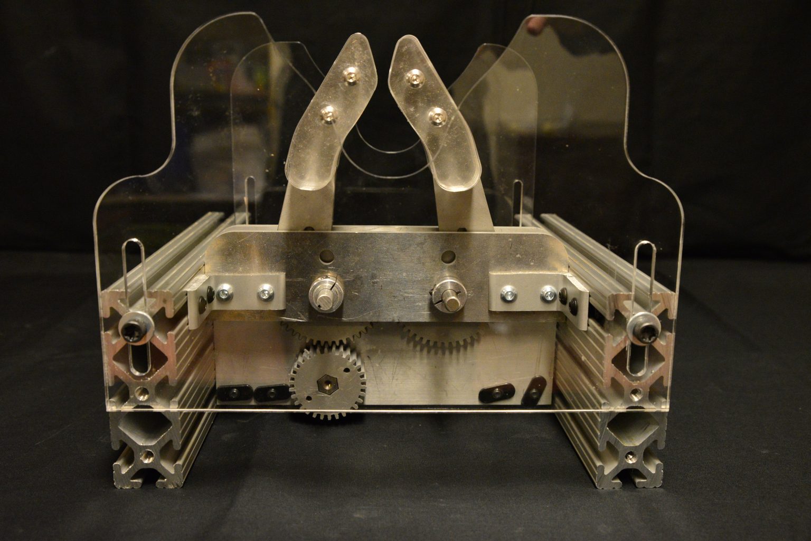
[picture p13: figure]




### 3.2.1 Diseño temprano (Unidad 001)

Una unidad prototipo temprana se muestra a continuación en acrílico cortado con láser. La Unidad 001 fue similar y se sometió a pruebas. La unidad 002, fabricada con un marco de metal 80/20, para abordar la durabilidad y maximizar la flexibilidad durante las pruebas, se somete a pruebas hoy.

La colección de imágenes de los primeros diseños se encuentra en esta carpeta

## 4 Diseño electrico

Esta sección muestra una descripción del conjunto mínimo de hardware requerido para controlar el ventilador como se describe en la otra documentación.

### 4.1 Motor y codificador

El sistema mecánico debe manejarse con un motor bajo control de circuito cerrado. Para la medición de retroalimentación, estamos utilizando un codificador de cuadratura en el motor y un potenciómetro (POT) en los brazos móviles para medir el ángulo absoluto.

### 4.1.1 Opciones de motor:

Motor DC cepillado con caja de cambios y retroalimentación de posición. Debería funcionar cualquier motor de par motor suficientemente alto con detección de ángulo, integrado o separado. La potencia se estima en 36 W o más, con un factor de seguridad recomendado.


Figure 2: Plates to support the bag

Figure 3: Unit 002-most updated design


Figure 4: Arquitectura del Sistema Electrico

Precaución: si se utiliza un motor paso a paso, la posición aún debe tomarse del sensor de ángulo para que los pasos omitidos no provoquen un desplazamiento de la posición

Precaución: el motor y el mecanismo, juntos, deben ser manejables hacia atrás para mover el mecanismo con la mano, quitar la bolsa e inmediatamente convertirla en una bolsa manual.

- Parámetros de funcionamiento nominales supuestos: Referencia a la documentación clínica: máximo 25 respiraciones por minuto (lpm) y hasta 1: 3 Inspiración: Relación de caducidad (relación I: E) (por ejemplo: bolsa apretada por 1 unidades de tiempo, bolsa relajada por 3 unidades de tiempo). Tenga en cuenta que los pacientes con COVID-19 pueden necesitar mayores proporciones I: E.
- Componente del prototipo: Andy Mark AM 2971 gearmotor. (https://sites.google.com/site/frc5064/parts/motors-and-gearboxes/-pg71-planetary-gearbox-with-rs775-motor-and-encoder)


Figure 5: Andy Mark AM 2971 gearmotor

Esto fue eliminado de un kit FIRST Robotics, es adecuado para pruebas, pero no ha sido probado para un uso seguro a largo plazo. Los constructores deberán buscar otro motor.

Si bien la máquina debe ser capaz de operar continuamente a un volumen corriente máximo y a un máximo de bpm, en la práctica, los profesionales médicos a menudo no operan con un gran volumen de marea y altos bpm simultáneamente. En funcionamiento normal, las relaciones I: E alrededor de 1: 2 y 12 lpm son un punto de diseño central decente. El volumen corriente en función de la posición necesita ser calibrado.

Precaución: en uso desplegado, el motor debe poder funcionar continuamente durante varios días, 100% de ciclo de trabajo. Esto puede requerir motores más grandes de lo esperado o mayor enfriamiento del motor para evitar el sobrecalentamiento.

### 4.2 Fuente de alimentación

Nominalmente, se espera que funcione una fuente de alimentación que pueda suministrar 12 V y 5 A. La desaceleración rápida del motor provoca picos de tensión de alimentación y debe evitarse mediante el diseño correcto del perfil de movimiento del motor. Se deben agregar condensadores a través de los cables de alimentación del puente H para una protección adicional.

Una fuente de alimentación alternativa sería utilizar una batería de automóvil con un cargador de batería de automóvil de 5 A conectado. Esto permitirá consumos de energía instantánea muy altos y absorción de picos de voltaje. La batería se duplicará como respaldo de ~ 2-3 horas en caso de pérdida de energía del edificio.

### 4.3 Controlador

Microcontrolador para temporización, medición y actuación: [Arduino Uno] (https://www.arduino.cc/en/Guide/ArduinoUno): fácilmente disponible y fácil de programar, con un amplio soporte y documentación en línea. Proporciona
6 pines A / D (para potenciómetros y sensores de presión) y 13 pines digitales de E / S, incluidas interrupciones de hardware dedicadas (para codificadores) y pines PWM para la conducción de puentes H.
Se pueden usar otros controladores validados por la industria, y podemos implementarlos en el futuro.

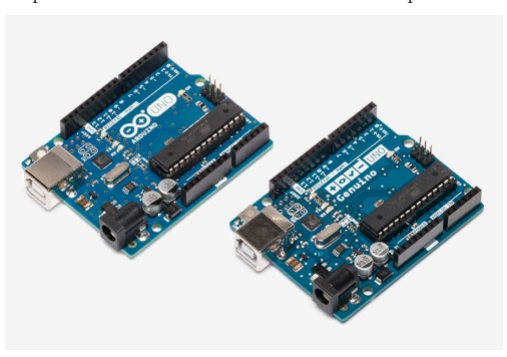
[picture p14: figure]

### 4.4 Motor Driver

Use cualquier controlador de motor con voltaje y corriente suficientes para cumplir con las especificaciones de potencia del motor. Los servocontroladores de circuito cerrado también se pueden emplear. Nuestra estrategia de control es PWM con un puente H. Para una implementación más rápida utilizando piezas
baratas y listas para usar, recomendamos un protector de motor compatible con Arduino.

Como referencia, estamos utilizando un [controlador de motor RoboClaw Solo] (https://www.pololu.com/product/3290) para controlar un motor de engranaje de CC cepillado. El firmware RoboClaw utiliza un controlador PID
de velocidad y un controlador PID de posición para ordenar al motor a una posición deseada a la velocidad
deseada. Los valores PID deben ajustarse de antemano. Otros controladores de motor con funciones similares funcionarán, no recomendamos ningún controlador específico.

### 4.5 Entradas

Los potenciómetros de la perilla de control (POT) deben ser todos de un solo giro, 10 K Ω. Un solo giro es permitir que ajustes específicos se marquen en la placa frontal.

Sensor de presión: recibe un voltaje proporcional a la presión en los pulmones del paciente. Se utiliza para determinar la presión máxima alcanzada durante la inspiración y para disparar cuando el paciente intenta respirar durante el modo de asistencia. El sensor de presión seleccionado debe ser diferencial (para detectar presiones negativas) con un rango de hasta 100 cm H 2 O. Este es un factor de seguridad 2x. Nuestros sensores provienen de Honeywell.

Nota sobre fontanería: el sensor de presión debe estar conectado al puerto de detección de la bolsa Ambu o en algún lugar del flujo de aire, lo más cerca posible del paciente, más allá de cualquier válvula.

POT 1 - Varía el volumen inspirado, establece la oscilación angular de los brazos. Durante la operación, cada brazo varía en un máximo de aproximadamente 20 grados, lo que corresponde a apretar completamente


Figure 6: RoboClaw Solo motor controller

una bolsa grande. Este dial varía la posición del 0% (completamente abierto) al 100% (completamente comprimido).

POT 2 - Varía el BPM. Esto establece la tasa de 0 a la BPM máxima dada en el documento clínico.

POT 3 - Varía la relación I: E. Rango según lo indicado en el documento clínico.

Nota: No es esencial que esto sea configurable, se puede seleccionar un valor mayor que 1: 1 y el POT se puede reutilizar como un umbral para la sobrepresión. (Varios médicos han indicado que variar I: E no es crítico).

POT 4 - Establece el umbral de presión para detectar el control de asistencia. Esto varía según lo descrito en el documento clínico.

Interruptor de botón pulsador: confirma la selección del usuario de la nueva configuración POT. Esta es una seguridad importante.

Interruptor - Encendido / apagado

E-stop: desactiva el sistema al instante.

Interruptor: selección de modo del volumen para ayudar al control.

Interruptor de límite: se utiliza para dirigir las posiciones de los brazos.

### 4.6 Salida

La pantalla LCD muestra la presión de la vía aérea en cm H2O. Otras funciones se pueden incorporar más adelante. Estamos utilizando una pantalla LCD de 20 × 4 caracteres, ya que esto mostrará la información mínima, descrita en la interfaz. Cualquier pantalla mejor que esto será suficiente.

4.7 El zumbador de alerta audible identificará múltiples condiciones de falla.

title: “Proyecto ventilador de emergencia del MIT (E-Vent)” output: pdf_document documentclass: article classoption: onecolumn pdf_document: latex_engine: pdflatex toc: true lof: true numberSections: true highlight: tango sectionsDepth: 3 chapters: True figPrefix: - “Fig.” - “Figs.” secPrefix: - “Section” -“Sections” fontsize: 12pt geometry: margin=0.5in autoEqnLabels: true cref: true crossref: true colorlinks: true —

## 5 Resultados de la prueba

Están trabajando con laboratorios de pruebas de animales certificados para llevar a cabo estudios en modelos animales bajo los protocolos aprobados por [IACUC-Comité Institucional de Cuidado y Uso de Animales] (https://olaw.nih.gov/resources/tutorial/iacuc.htm). Se eligió un modelo porcino ya que los cerdos tienen un sistema respiratorio que es más similar al de los seres humanos. Esto es esencial para evaluar el rendimiento y la seguridad del sistema. Nos gustaría reconocer de forma anónima al personal del laboratorio por sus incansables esfuerzos, y a los donantes que están permitiendo esta rápida ampliación de la experimentación con animales.

### 5.1 Estudio 1 - 20 de marzo de 2020

El estudio porcino número 1 se realizó en una instalación de investigación líder en el área de Boston. Además del personal de la instalación (veterinarios, tecnólogos y estudio), nuestro equipo en el lugar consistía en médicos de medicina de emergencia y anestesia que trabajaban junto con ingenieros mecánicos, de fabricación, controles e ingeniería eléctrica. Los objetivos de este estudio fueron los siguientes:

- Realice una prueba funcional del prototipo MIT E-Vent Unit 001.
- Compare la ventilación con el E-Vnet con la de un sistema de ventilación Puritan Bennet 840 (año modelo 2016, Medtronic) (https://www.medtronic.com/covidien/en-us/products/mechanical-ventilation/puritan-%20bennett-840-ventilator.html) gentilmente prestado a nosotros.

### 5.1.1 Aprendizajes clave (se obtendrán más resultados)

- Identificamos deficiencias en el diseño de corte totalmente láser. Ya hemos hecho la transición a un diseño de marco de metal.
- Definimos con mayor precisión los parámetros clave relacionados con los requisitos de energía para un sistema de accionamiento.
- Investigamos posibles estrategias de control e identificamos requisitos clave de UI / UX, así como factores humanos.
- Determinamos las presiones clave cuando se conecta a un pulmón real y con un conjunto de PEEP.

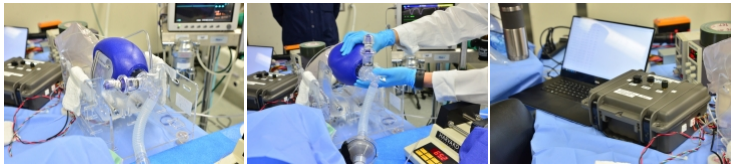
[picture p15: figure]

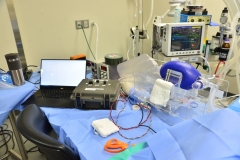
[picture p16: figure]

### 5.1.2 Próximos pasos

El próximo estudio llevará a cabo una prueba funcional de la Unidad 002 en un modelo porcino similar.

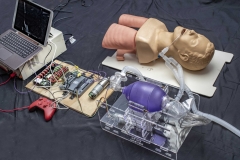
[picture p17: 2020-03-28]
docs/img/early-design-001/thumbs_MIT_E_Vent_ComputerControlBoardVentDummy_001.jpg

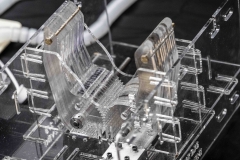
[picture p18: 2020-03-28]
docs/img/early-design-001/thumbs_MIT_E_Vent_Fingers_unit-001.jpg

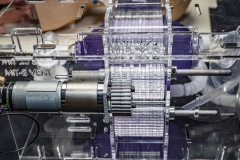
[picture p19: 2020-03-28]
docs/img/early-design-001/thumbs_MIT_E_Vent_BottomView_001.jpg

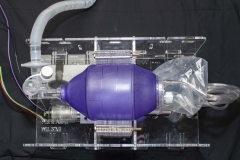
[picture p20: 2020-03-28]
docs/img/early-design-001/thumbs_MIT_E_Vent_TopView_001.jpg

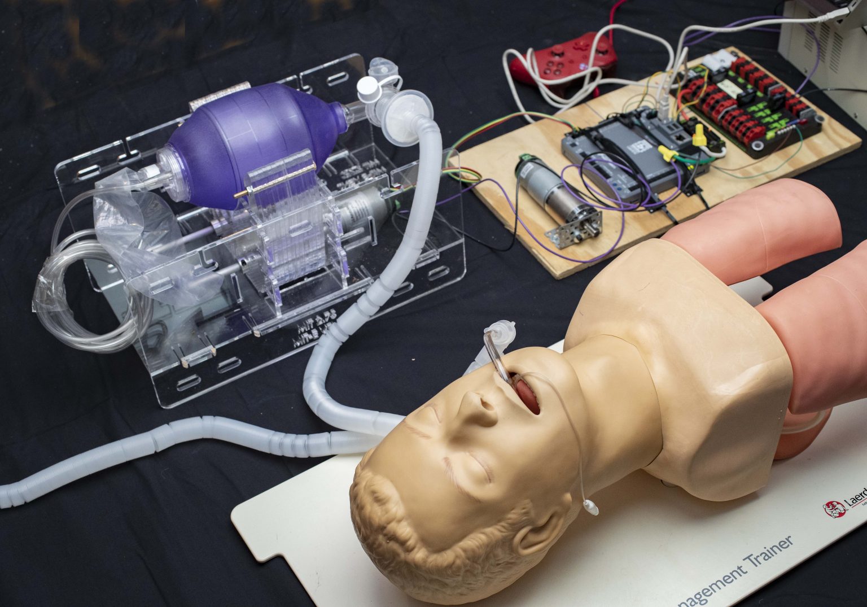
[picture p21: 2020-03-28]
docs/img/early-design-001/MIT_E_Vent_Mannequin_ControllerBoard.jpg

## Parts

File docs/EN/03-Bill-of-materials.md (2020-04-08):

---
title: "MIT Emergency Ventilator (E-Vent) Project"
output: pdf_document
documentclass: article
classoption: onecolumn
pdf_document:
latex_engine: pdflatex
toc: true
lof: true
numberSections: true
highlight: tango
sectionsDepth: 3
chapters: True
figPrefix:
  - "Fig."
  - "Figs."
secPrefix:
  - "Section"
  - "Sections"
fontsize: 12pt
geometry: margin=0.5in
autoEqnLabels: true
cref: true
crossref: true
colorlinks: true
---

# Mechanical design

 How does the E-vent looks like?

 See how the [emergency ventilator works here](https://e-vent.mit.edu/wp-content/uploads/2020/03/002-bench-testing-scaled-1.mp4)

## Files to download

Follow this [link](../../src) where there are all the .dxf files.

**This section documents the mechanical design of the MIT E-Vent.**

***Please understand that we are designing, testing and posting information as fast as we can. We have no hidden information and more detailed plans will post as soon as we draw them!***

**Note:** Any mechanical design must meet the specifications outlined in the [Getting started section](./02-Getting-started.md).

***This is a prototype.*** We are in process of testing and refining this concept design to increase robustness. The basic concept consists of two arms that gently close in sync to compress the bag. This must be coupled with a closed loop control system. Major mechanical design requirements included:

- Be nice to your bag and its hoses! Up to 2x7x24X60x30 = 604,800 cycles.
- Fail-Safe operation! If the machine fails, a clinician must be able to convert to manual bagging.
- Keep It Simple & Make It Super! Enable others to fabricate.
- Many drive motor possibilities! Enable multiple motors and configurations.

The [Units version 002](../img/mit-e-vent-unit-002-setup.jpg) shown here were developed to maximize flexibility during testing, so that the bag and motor position could be adjusted. None of this adjustability is needed once a particular bag is selected.

The basic dimensions are now set and any skilled mechanical designer will be able to execute this design and adjust it to suit locally available materials and fabrication technologies. 

We have ready access to waterjet and laser cutters and 80/20 components, however these parts can be CNC milled and bolted and welded to your specification

## Documentation useful pictures

***Caution: Forces and torques are much higher than expected when an Ambu bag is connected to a human respiratory system pressures can range up to 40 cm H2O and, potentially, even higher depending on breath rate. There must be a pressure release valve set at 40 cm H2O; without this higher pressures will risk permeant injury or death. Diseased lungs can have compliance on the order of 10x lower than that of healthy patients and this further compounds the problem.***

Gear strain for actuating arms
device-003
device-002
device-001
Bag exposed design

Plates to support the bag

Unit 002-most updated design

### Early design (Unit 001)

An early prototype unit is show below in laser cut acrylic. Unit 001 was similar and underwent testing. Unit 002 been fabricated with an 80/20 metal frame, to address durability and maximise flexibility during testing, is undergoing testing today.

The collection of pictures from early designs are found [in this folder](../img)

# Electrical Design

This section shows a description of the minimum hardware set required to control the ventilator as described in the other documentation.

Electrical System Architecture

## Motor & Encoder

The mechanical system should be driven with a motor under closed loop control. For feedback measurement, we are using a quadrature encoder on the motor, and a potentiometer (POT) on the moving arms to measure the absolute angle.

### Motor Options: 

Brushed DC motor with gearbox and position feedback. Any sufficiently high-torque, back-driveable motor with angle sensing, integrated or separated, should work. Power is estimated at 36 W or greater, with a safety factor recommended.

***Caution: If a stepper motor is used, position should still be taken from the angle sensor so that missed steps do not cause position drift***

***Caution: The motor and mechanism, together, must be back drivable in order to move the mechanism by hand, remove the bag and immediately convert to manual bagging.***

- Assumed nominal operating parameters: Referencing clinical documentation: max 25 breath-per-minute (bpm), and up to a 1:3 Inspiration: Expiration Ratio (I:E ratio) (ex: bag squeezed for 1 time units, bag relaxed for 3 time units). Note that COVID-19 patients may need greater I:E ratios.

- Prototype component: [Andy Mark AM 2971 gearmotor](https://sites.google.com/site/frc5064/parts/motors-and-gearboxes/-pg71-planetary-gearbox-with-rs775-motor-and-encoder). 

    Andy Mark AM 2971 gearmotor

  This was scavenged from a FIRST Robotics kit, it is suitable for testing, **but has not been proved for safe longer-term use. Builders will need to source another motor.**

While the machine should be capable of operating continuously at max tidal volume and max bpm, in practice medical professionals often do not operate with large tidal volume and high bpm simultaneously. In normal operation, I:E ratios around 1:2 and 12 bpm are a decent central design point. Tidal volume as a function of position needs to be calibrated.

***Caution: In deployed use, the motor must be able to operate continuously for several days, 100% duty cycle. This may require larger motors than expected or increased motor cooling to prevent overheating.***

## Power Supply

Nominally, a power supply that can deliver 12 V and 5 A is expected to work. Rapid deceleration of the motor causes supply-voltage spikes and must be avoided via correct motor motion profile design. Capacitors should be added across the H-Bridge power leads for extra protection. 

An alternate power supply would be to use a car battery with a 5 A car battery charger connected. This will allow for very high instantaneous power draws and voltage spike absorption. The battery will double as a ~2-3 hour backup in case of building power loss.

## Controller

Microcontroller for timing, measuring, and actuating: [Arduino Uno](https://www.arduino.cc/en/Guide/ArduinoUno) – readily available and easy to program, with extensive online support and documentation. It provides 6 A/D pins (for potentiometers and pressure sensors) and 13 digital I/O pins, including dedicated hardware interrupts (for encoders) and PWM pins for H-bridge driving. Other industry validated controllers can be used, and we may implement them in the future.
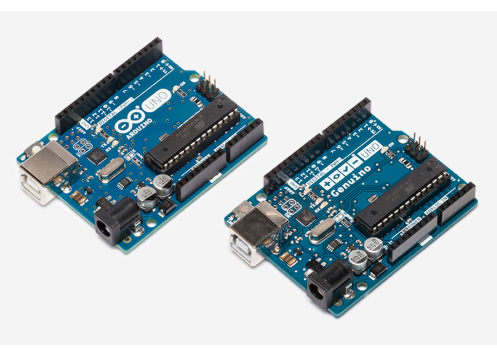
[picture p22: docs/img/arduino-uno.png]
Arduino Uno
    

## Motor Driver

Use any motor driver with sufficient voltage and current ratings to meet the motor power specifications. Closed loop servo controllers can also be employed. Our control strategy is PWM with a H Bridge. For fastest implementation using cheap, off-the-shelf parts, we recommend an Arduino compatible motor shield.

For reference, we are using a [RoboClaw Solo motor controller](https://www.pololu.com/product/3290) to control a brushed DC gear motor. The RoboClaw firmware uses a velocity PID controller and a position PID controller to command the motor to a desired position at a desired velocity. The PID values must be tuned in advance. Other motor controllers with similar functions will work, we do not recommend any specific controller.

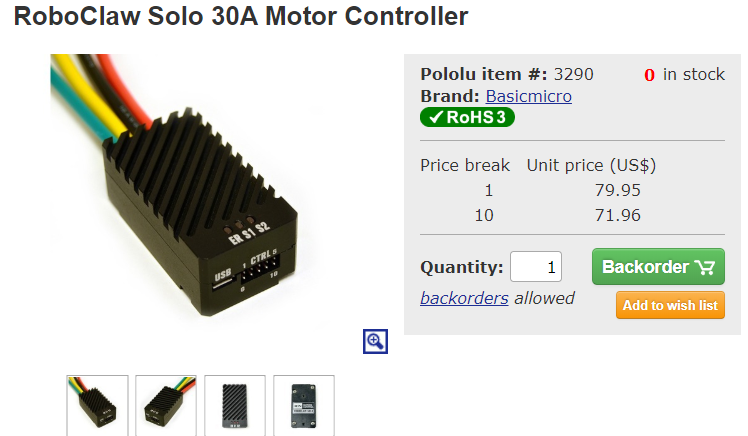
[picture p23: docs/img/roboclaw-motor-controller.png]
RoboClaw Solo motor controller
  

## Inputs

Control knob potentiometers (POTs) should all be single turn, 10 K$\Omega$. Single turn is to allow for specific settings to be marked on the face plate.

Pressure sensor – Receives a voltage proportional to the pressure in the patient’s lungs. Used to determine max pressure reached during inspiration, and to trigger when the patient is attempting to breathe in during assist mode. Pressure sensor selected should be differential (to sense negative pressures) with a range of up to 100 cm H$_2$O. This is a 2x safety factor. Our sensors are sourced from Honeywell.

***Note on Plumbing: The pressure sensor must be connected to the Ambu bag’s sensing port or somewhere in the airflow, as close as possible to the patient, past any valves.***

**POT 1** – Varies inspired volume, sets angular oscillation of the arms. During operation, each arm varies by a maximum of approximately 20 grades, corresponding to fully squeezing a large bag. This dial varies position from 0% (fully open) to 100% (fully compressed).

**POT 2 **– Varies the BPM. This sets the rate from 0 to the maximum BPM given in the clinical document.

**POT 3** – Varies the I:E ratio. Range as given in the clinical document.

Note: It is not essential that this be settable, one value greater than 1:1 can be selected and the POT repurposed as a threshold for over pressure. (Multiple clinicians have indicated that varying I:E is not critical.)

**POT 4**– Sets the pressure threshold for detecting assist control. This varies as described in the clinical document.

Pushbutton Switch – Confirms user selection of new POT setting. This is an important safety.

Switch – Power on / off

E-stop – Instantly deactivates the system.

Switch – Mode selection from volume to assist control.

Limit Switch – Used for homing the arms positions.

## Output

LCD screen displays airway pressure in cm H2O. Other functions can be incorporated later. We are using a 20×4 character LCD display as this will display the minimum information, described in under interface. Any display better than this will be sufficient.

Audible alert buzzer will identify multiple fault conditions.

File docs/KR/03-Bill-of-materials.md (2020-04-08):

---
title: "Proyecto ventilador de emergencia del MIT (E-Vent)"
output: pdf_document
documentclass: article
classoption: onecolumn
pdf_document:
latex_engine: pdflatex
toc: true
lof: true
numberSections: true
highlight: tango
sectionsDepth: 3
chapters: True
figPrefix:
  - "Fig."
  - "Figs."
secPrefix:
  - "Section"
  - "Sections"
fontsize: 12pt
geometry: margin=0.5in
autoEqnLabels: true
cref: true
crossref: true
colorlinks: true
---

# Diseño Mecanico

 Como es el E-vent en accion? 

 Para que veas como funciona E-vent [dirigete aqui](https://e-vent.mit.edu/wp-content/uploads/2020/03/002-bench-testing-scaled-1.mp4)

## Ficheros para descargar

Sigue este [link](../../src) donde estan todos los .dxf ficheros.

**Esta sección documenta el diseño mecánico del MIT E-Vent.**

**Por favor, comprenda que estamos diseñando, probando y publicando información lo más rápido posible. ¡No tenemos información oculta y se publicarán planes más detallados tan pronto como los dibujemos!***

**Nota:** Cualquier diseño mecánico debe cumplir con las especificaciones descritas en la [Sección de inicio](./ 02-Getting-started.md).

**Este es un prototipo.** Estamos en proceso de probar y refinar este diseño conceptual para aumentar la robustez. El concepto básico consiste en dos brazos que se cierran suavemente sincronizados para comprimir la bolsa. Esto debe combinarse con un sistema de control de circuito cerrado. Los principales requisitos de diseño mecánico incluyen:

- ¡Sé amable con tu bolso y sus mangueras! Hasta 2x7x24X60x30 = 604,800 ciclos.
- ¡Operación a prueba de fallas! Si la máquina falla, un médico debe poder realizar la conversión a embolsado manual.
- ¡Mantenlo simple y hazlo súper! Permitir que otros fabriquen.
- ¡Muchas posibilidades de motor de accionamiento! Habilite múltiples motores y configuraciones.

Las [Unidades versión 002](../img/mit-e-vent-unit-002-setup.jpg) que se muestran aquí se desarrollaron para maximizar la flexibilidad durante las pruebas, de modo que la posición de la bolsa y el motor pudieran ajustarse. Nada de esta capacidad de ajuste es necesaria una vez que se selecciona una bolsa en particular.

Ahora se establecen las dimensiones básicas y cualquier diseñador mecánico experto podrá ejecutar este diseño y ajustarlo para adaptarse a los materiales disponibles localmente y las tecnologías de fabricación.

Tenemos acceso inmediato a cortadores de chorro de agua y láser y componentes 80/20, sin embargo, estas piezas se pueden fresar, atornillar y soldar con CNC según sus especificaciones.

## Documentación de imágenes útiles

***Precaución: las fuerzas y los pares son mucho más altos de lo esperado cuando una bolsa Ambu está conectada a un sistema respiratorio humano, las presiones pueden variar hasta 40 cm H2O y, potencialmente, incluso más, dependiendo de la frecuencia respiratoria. Debe haber una válvula de liberación de presión establecida a 40 cm H2O; sin esto, las presiones más altas correrán el riesgo de lesiones permanentes o la muerte. Los pulmones enfermos pueden tener un cumplimiento del orden de 10 veces menor que el de los pacientes sanos y esto agrava aún más el problema.***

Gear strain for actuating arms
device-003
device-002
device-001
Bag exposed design

Plates to support the bag

Unit 002-most updated design

### Diseño temprano (Unidad 001)

Una unidad prototipo temprana se muestra a continuación en acrílico cortado con láser. La Unidad 001 fue similar y se sometió a pruebas. La unidad 002, fabricada con un marco de metal 80/20, para abordar la durabilidad y maximizar la flexibilidad durante las pruebas, se somete a pruebas hoy.

La colección de imágenes de los primeros diseños se encuentra [en esta carpeta](../img)

# Diseño electrico

Esta sección muestra una descripción del conjunto mínimo de hardware requerido para controlar el ventilador como se describe en la otra documentación.

Arquitectura del Sistema Electrico

## Motor y codificador

El sistema mecánico debe manejarse con un motor bajo control de circuito cerrado. Para la medición de retroalimentación, estamos utilizando un codificador de cuadratura en el motor y un potenciómetro (POT) en los brazos móviles para medir el ángulo absoluto.

### Opciones de motor:

Motor DC cepillado con caja de cambios y retroalimentación de posición. Debería funcionar cualquier motor de par motor suficientemente alto con detección de ángulo, integrado o separado. La potencia se estima en 36 W o más, con un factor de seguridad recomendado.

**Precaución: si se utiliza un motor paso a paso, la posición aún debe tomarse del sensor de ángulo para que los pasos omitidos no provoquen un desplazamiento de la posición**

**Precaución: el motor y el mecanismo, juntos, deben ser manejables hacia atrás para mover el mecanismo con la mano, quitar la bolsa e inmediatamente convertirla en una bolsa manual.**

- Parámetros de funcionamiento nominales supuestos: Referencia a la documentación clínica: máximo 25 respiraciones por minuto (lpm) y hasta 1: 3 Inspiración: Relación de caducidad (relación I: E) (por ejemplo: bolsa apretada por 1 unidades de tiempo, bolsa relajada por 3 unidades de tiempo). Tenga en cuenta que los pacientes con COVID-19 pueden necesitar mayores proporciones I: E.

- Componente del prototipo: [Andy Mark AM 2971 gearmotor](https://sites.google.com/site/frc5064/parts/motors-and-gearboxes/-pg71-planetary-gearbox-with-rs775-motor-and-encoder). 

    Andy Mark AM 2971 gearmotor

  Esto fue eliminado de un kit FIRST Robotics, es adecuado para pruebas, **pero no ha sido probado para un uso seguro a largo plazo. Los constructores deberán buscar otro motor.**

Si bien la máquina debe ser capaz de operar continuamente a un volumen corriente máximo y a un máximo de bpm, en la práctica, los profesionales médicos a menudo no operan con un gran volumen de marea y altos bpm simultáneamente. En funcionamiento normal, las relaciones I: E alrededor de 1: 2 y 12 lpm son un punto de diseño central decente. El volumen corriente en función de la posición necesita ser calibrado.

**Precaución: en uso desplegado, el motor debe poder funcionar continuamente durante varios días, 100% de ciclo de trabajo. Esto puede requerir motores más grandes de lo esperado o mayor enfriamiento del motor para evitar el sobrecalentamiento.**

## Fuente de alimentación

Nominalmente, se espera que funcione una fuente de alimentación que pueda suministrar 12 V y 5 A. La desaceleración rápida del motor provoca picos de tensión de alimentación y debe evitarse mediante el diseño correcto del perfil de movimiento del motor. Se deben agregar condensadores a través de los cables de alimentación del puente H para una protección adicional.

Una fuente de alimentación alternativa sería utilizar una batería de automóvil con un cargador de batería de automóvil de 5 A conectado. Esto permitirá consumos de energía instantánea muy altos y absorción de picos de voltaje. La batería se duplicará como respaldo de ~ 2-3 horas en caso de pérdida de energía del edificio.

## Controlador

Microcontrolador para temporización, medición y actuación: [Arduino Uno] (https://www.arduino.cc/en/Guide/ArduinoUno): fácilmente disponible y fácil de programar, con un amplio soporte y documentación en línea. Proporciona 6 pines A / D (para potenciómetros y sensores de presión) y 13 pines digitales de E / S, incluidas interrupciones de hardware dedicadas (para codificadores) y pines PWM para la conducción de puentes H. Se pueden usar otros controladores validados por la industria, y podemos implementarlos en el futuro.
    Arduino Uno

## Motor Driver

Use cualquier controlador de motor con voltaje y corriente suficientes para cumplir con las especificaciones de potencia del motor. Los servocontroladores de circuito cerrado también se pueden emplear. Nuestra estrategia de control es PWM con un puente H. Para una implementación más rápida utilizando piezas baratas y listas para usar, recomendamos un protector de motor compatible con Arduino.

Como referencia, estamos utilizando un [controlador de motor RoboClaw Solo] (https://www.pololu.com/product/3290) para controlar un motor de engranaje de CC cepillado. El firmware RoboClaw utiliza un controlador PID de velocidad y un controlador PID de posición para ordenar al motor a una posición deseada a la velocidad deseada. Los valores PID deben ajustarse de antemano. Otros controladores de motor con funciones similares funcionarán, no recomendamos ningún controlador específico.

  RoboClaw Solo motor controller

## Entradas

Los potenciómetros de la perilla de control (POT) deben ser todos de un solo giro, 10 K $\Omega$. Un solo giro es permitir que ajustes específicos se marquen en la placa frontal.

Sensor de presión: recibe un voltaje proporcional a la presión en los pulmones del paciente. Se utiliza para determinar la presión máxima alcanzada durante la inspiración y para disparar cuando el paciente intenta respirar durante el modo de asistencia. El sensor de presión seleccionado debe ser diferencial (para detectar presiones negativas) con un rango de hasta 100 cm H $_2$ O. Este es un factor de seguridad 2x. Nuestros sensores provienen de Honeywell.

**Nota sobre fontanería: el sensor de presión debe estar conectado al puerto de detección de la bolsa Ambu o en algún lugar del flujo de aire, lo más cerca posible del paciente, más allá de cualquier válvula.**

**POT 1** - Varía el volumen inspirado, establece la oscilación angular de los brazos. Durante la operación, cada brazo varía en un máximo de aproximadamente 20 grados, lo que corresponde a apretar completamente una bolsa grande. Este dial varía la posición del 0% (completamente abierto) al 100% (completamente comprimido).

**POT 2** - Varía el BPM. Esto establece la tasa de 0 a la BPM máxima dada en el documento clínico.

**POT 3** - Varía la relación I: E. Rango según lo indicado en el documento clínico.

Nota: No es esencial que esto sea configurable, se puede seleccionar un valor mayor que 1: 1 y el POT se puede reutilizar como un umbral para la sobrepresión. (Varios médicos han indicado que variar I: E no es crítico).

**POT 4** - Establece el umbral de presión para detectar el control de asistencia. Esto varía según lo descrito en el documento clínico.

Interruptor de botón pulsador: confirma la selección del usuario de la nueva configuración POT. Esta es una seguridad importante.

Interruptor - Encendido / apagado

E-stop: desactiva el sistema al instante.

Interruptor: selección de modo del volumen para ayudar al control.

Interruptor de límite: se utiliza para dirigir las posiciones de los brazos.

## Salida

La pantalla LCD muestra la presión de la vía aérea en cm H2O. Otras funciones se pueden incorporar más adelante. Estamos utilizando una pantalla LCD de 20 × 4 caracteres, ya que esto mostrará la información mínima, descrita en la interfaz. Cualquier pantalla mejor que esto será suficiente.

El zumbador de alerta audible identificará múltiples condiciones de falla.

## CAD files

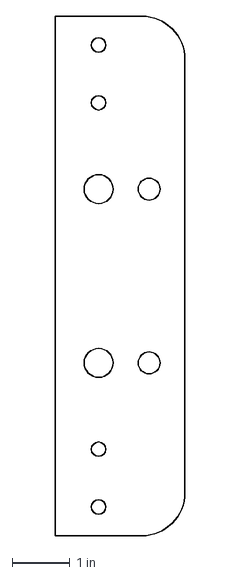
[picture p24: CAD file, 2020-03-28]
src/Finger Mount.dxf
2.25 x 9.00 in

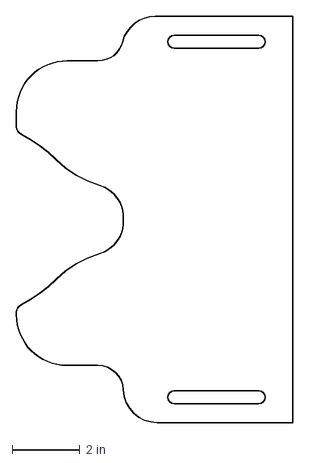
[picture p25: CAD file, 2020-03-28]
src/Bag Support End.dxf
8.16 x 12.0 in

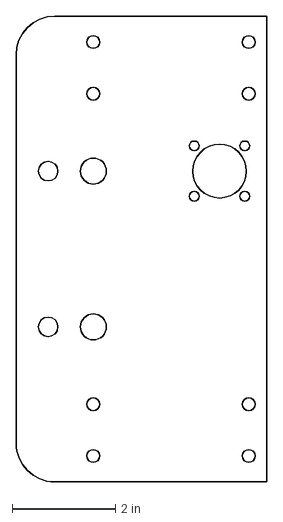
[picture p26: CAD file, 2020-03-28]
src/Motor and Finger Mount.dxf
4.85 x 9.00 in

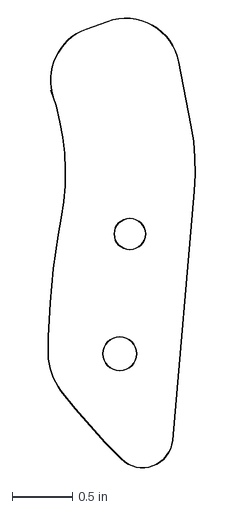
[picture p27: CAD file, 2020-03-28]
src/Finger Tip.dxf
1.27 x 3.77 in

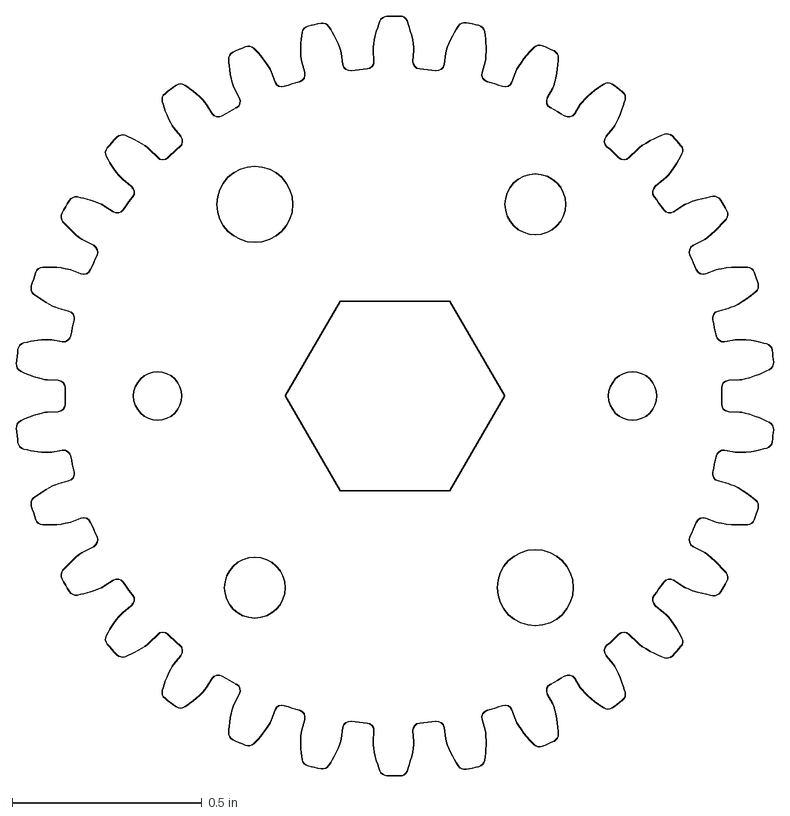
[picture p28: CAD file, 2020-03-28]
src/Drive Gear.dxf
1.99 x 2.00 in

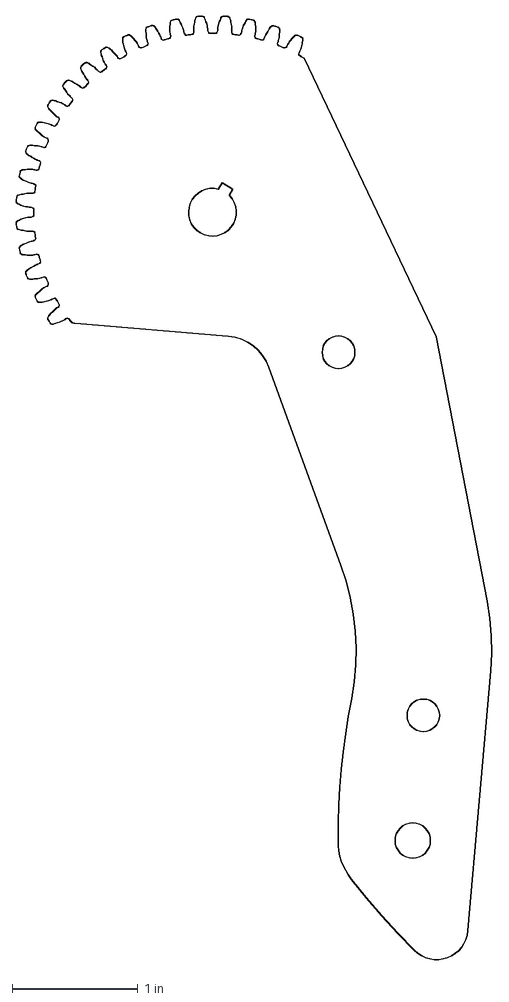
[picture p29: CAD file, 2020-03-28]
src/Finger.dxf
3.79 x 7.53 in

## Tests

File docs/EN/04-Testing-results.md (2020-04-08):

---
title: "MIT Emergency Ventilator (E-Vent) Project"
output: pdf_document
documentclass: article
classoption: onecolumn
pdf_document:
latex_engine: pdflatex
toc: true
lof: true
numberSections: true
highlight: tango
sectionsDepth: 3
chapters: True
figPrefix:
  - "Fig."
  - "Figs."
secPrefix:
  - "Section"
  - "Sections"
fontsize: 12pt
geometry: margin=0.5in
autoEqnLabels: true
cref: true
crossref: true
colorlinks: true
---

# Testing results

They  are working with certified animal testing labs to conduct studies in animal models under [IACUC-Institutional Animal Care and Use Committee](https://olaw.nih.gov/resources/tutorial/iacuc.htm) approved protocols. A porcine model was chosen as pigs have a respiratory systems that is most similar to human beings. **This is essential in order to evaluate system performance and safety. We would like to anonymously acknowledge the laboratory staff for their tireless efforts, and the donors who are enabling this rapid scale-up of animal testing.**

## Study 1 – 20 March 2020
Porcine study Nr 1 was conducted at a leading research facility in the Boston area. In addition to the facility staff (veterinarians, technologists, and Study), our on-site team consisted of Emergency Medicine and Anesthesia physicians working along side mechanical design, manufacturing, controls, and electrical engineers. The goals of this study were as follows:

- Conduct a functional test of the prototype MIT E-Vent Unit 001.
- Compare ventilation with the E-Vnet to that of a Puritan Bennet 840 Ventilator system (2016 model year, [Medtronic](https://www.medtronic.com/covidien/en-us/products/mechanical-ventilation/puritan-bennett-840-ventilator.html)) graciously loaned to us.

### Key Learnings (more results will be forthcoming)

- We identified deficiencies in the all-laser cut design. We have already transitioned to a metal frame design.
- We more accurately defined key parameters related to power requirements for a drive system.
- We investigated potential control strategies and identified key UI/UX requirements as well as human factors.
- We determined key pressures when connected to a real lung and with PEEP set.

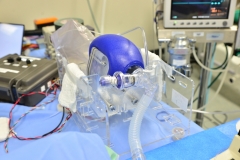
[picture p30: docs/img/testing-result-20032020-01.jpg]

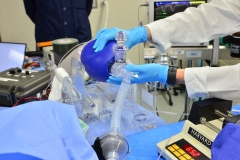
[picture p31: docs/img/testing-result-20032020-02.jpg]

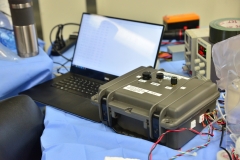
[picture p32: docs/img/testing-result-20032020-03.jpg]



### Next Steps

The next study will conduct a functional test Unit 002 in a similar porcine model.

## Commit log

2020-03-28 documentation-e-vent from MIT
    [Bag Support End.dxf, Drive Gear.dxf, Finger Mount.dxf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]
2020-03-28 relocating dxf files
    [Bag Support End.dxf, Drive Gear.dxf, Finger Mount.dxf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]
2020-04-06 Similar to just now on medical-shields-for-3d-printing, correct local C:\ pc file links to ../somewhere etc. proper universal links that work on the web and app. Also some minor issues caught and fix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
2020-04-16 This is a first working model, to prove out our simplified design for per-language metadata. There are also key additions in this upgrade, three new fields of definite importance, and always having b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
    A side note is that this is being pushed to the _master_ branch, and the moment will soon end for doing that, as constructing content will move to the very familiar and effective way that most pr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
